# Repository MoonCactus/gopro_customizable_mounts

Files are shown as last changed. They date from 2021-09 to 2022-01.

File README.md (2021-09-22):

This is the **official** and popular "GoPro customizable mounts, and a library to expand"

It is an openscad script than can generate all sorts of custom gopro mounts. This is useful both when space is a constraint and to improve stiffness over complicated multipart "official" gopro linked mount bits.

You can use Thingiverse "customizer" (when it works) to generate all sorts of shapes to suit your needs.

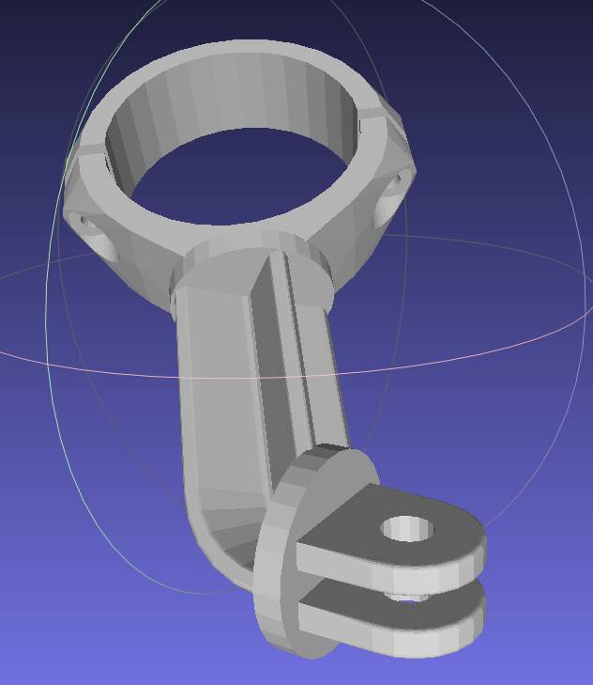
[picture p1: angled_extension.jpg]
Example of generated design


Licence is CC-BY-NC 2013 by jeremie.francois@gmail.com

  * https://www.linkedin.com/in/jeremiefrancois/
  * https://www.thingiverse.com/thing:62800
  * Make yours with https://www.thingiverse.com/apps/customizer/run?thing_id=62800
  * https://www.tridimake.com

It slices neatly with the following parameters

  * 0.1 mm layers (for better look & more compact FDM) -- 0.15 is still OK (and faster)
  * 0.8 mm walls (loops->infill->perimeters)
  * 0.8 mm bottom/top
  * 100% fill (probably safer, though 30% is quite OK)

Better use PETG instead of PLA for heat resistance.

History
  * Rev 1.2: added vvertical angle option for extension, free head rotation and rounded baseplate when needed
  * Rev 1.1: added horizontal angle option for extension
  * Rev 1.03: examples and first release (20130317-1234)
  * Rev 1.02: added handle/bar mount and rounded the angles of the rod mount
  * Rev 1.01: fixed printing angle vs captive nut slot, added a slight freeplay

Example of parameters

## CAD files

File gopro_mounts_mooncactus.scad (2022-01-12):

/* [Main] */

// First head kind ("example" show them all but is not printable)
gopro_primary_kind="triple"; // [example1,example2,triple,double]
// Sedond head kind (only for the triple or double primary kind)
gopro_secondary_kind="tripod_small"; // [double,triple,rod,clamp,tripod_small,tripod_large,plate,none]
// If you rotate the seconday head you will probably need to enable support to print it
gopro_secondary_rotation=0; // [0:180]

// Optional, possibly bent axis-to-axis extension rod (length cannot be less than 21mm).
gopro_ext_len=50;
// Thickness of the extension rod walls (2 to 6mm are good values)
gopro_ext_th=2;
// Angle at the base of the extension
gopro_ext_bend_angle=50; // [0:90]
// Twist at the base of the extension
gopro_ext_twist=0; // [0:180]

// How thick are the mount walls
gopro_wall_th= 3;

/* [Rod and captive nut] */

// This tab is useful only if you have selected "rod" as the secondary head. Optional rod diameter (also the captive nut internal diameter)
gopro_captive_rod_id= 3.8;
// Angle the rod makes with the axis (0 is colinear, 90 is a right angle)
gopro_captive_rod_angle= 45; // [0:90]
// Optional captive nut thickness with freeplay (tightest would be 3.2)
gopro_rod_nut_th= 3.6;
// Optional captive nut diameter with freeplay (from corner to corner)
gopro_rod_nut_od= 8.05;

/* [Clamp/bar mount] */

// This tab is useful only if you have selected "clamp" as the secondary head.  Optional (handle)bar diameter
gopro_bar_rod_d= 35;
// How thick is the ring around the bar
gopro_bar_th= 4;
// How big is the gap between the jaws
gopro_bar_gap= 2;
// Bar screw diameter
gopro_bar_screw_d= 3;
// Diameter of the head of the screw
gopro_bar_screw_head_d= 6.4;
// Diameter of the nut of the screw from corner to corner (can be zero)
gopro_bar_screw_nut_d= 6.25;
// How thick are the shoulders on which to bolt (each side)
gopro_bar_screw_shoulder_th=5;
// Whether to reverse the bolt orientation (from which side you will screw the bolt, defaut is from the joint)
gopro_bar_screw_reversed=0; // [0:false, 1:true]

/* [Baseplate] */

// This tab is useful only if you have selected "plate" as the secondary head. Increase gopro_wall_th for sturdier shape. Plate main length:
plate_len=40;
// Width of the plate, or zero for the exact arm section (it makes the shape easier to print, but a possibly unstable base)
plate_width=0;
// Diameter of the plate screws
plate_screw_d=3.1;
// Distance from screws to the exterior of the baseplate (ie. relative to plate_len)
plate_screw_margin_outer=5;
// Space betwen optional pairs of screws. Zero to have only one screw on each side.
plate_screw_pair_spacing=0;
// Make the screw pairs into slots (needs positive plate_screw_pair_spacing). Useful for straps, for example.
plate_strap_slot=0; // [0:false, 1:true]
// Gap to leave for a strap be be sled between the plate and the rest of the shape (makes it harder to print).
plate_strap_gap=0;

/* [Hidden] */

// The gopro connector itself (you most probably do not want to change this but for the first two)

// The locking nut on the gopro mount triple arm mount (keep it tight)
gopro_nut_d= 9.2;
// How deep is this nut embossing (keep it small to avoid over-overhangs)
gopro_nut_h= 2;
// Hole diameter for the two-arm mount part
gopro_holed_two= 5.2;
// Hole diameter for the three-arm mount part
gopro_holed_three= 5.5;
// Thickness of the internal arm in the 3-arm mount part
gopro_connector_th3_middle= 3.2;
// Thickness of the side arms in the 3-arm mount part
gopro_connector_th3_side= 2.75;
// Thickness of the arms in the 2-arm mount part
gopro_connector_th2= 2.85;
// The gap in the 3-arm mount part for the two-arm
gopro_connector_gap= 2.95;
// How round are the 2 and 3-arm parts
gopro_connector_roundness= 1;

// Hole diameter for small tripod mount screws (tight-fit)
tripod_small_d=5.5;
// Hole diameter for large tripod mount screws (tight-fit)
tripod_large_d=8.4;
// Tripod base height
tripod_screw_depth=12;
// Tripod base diameter
tripod_base_d=25;

// These two settings only helps against geometrical issues (non-manifold), do not change !
gopro_connector_wall_tol=0.5+0;
gopro_tol=0.04+0;

// Can be queried from the outside
gopro_connector_z= 2*gopro_connector_th3_side+gopro_connector_th3_middle+2*gopro_connector_gap;
gopro_connector_x= gopro_connector_z;
gopro_connector_y= gopro_connector_z/2+gopro_wall_th;

///////////////////////////////////////////////////////////////////////
//
// GoPro Hero mount and joint (gopro_mounts_mooncactus.scad) - Rev 1.1
//
///////////////////////////////////////////////////////////////////////
//
// CC-BY-NC 2013 jeremie.francois@gmail.com
// https://www.linkedin.com/in/jeremiefrancois/
// https://www.thingiverse.com/thing:62800
// https://www.tridimake.com

// It slices neatly with the following parameters
//
// 0.1 mm layers (for better look & more compact FDM) -- 0.15 is still OK (and faster)
// 0.8 mm walls (loops->infill->perimeters)
// 0.8 mm bottom/top
// 100% fill (probably safer, though 30% is quite OK)
// Better use PETG instead of PLA for heat resistance.
//
// Rev 1.3: added tripod and base plate end shapes
// Rev 1.2: added vertical angle option for extension, free head rotation and rounded baseplate when needed
// Rev 1.1: added horizontal angle option for extension
// Rev 1.03: examples and first release (20130317-1234)
// Rev 1.02: added handle/bar mount and rounded the angles of the rod mount
// Rev 1.01: fixed printing angle vs captive nut slot, added a slight freeplay

/* ****************************************************************

HOW TO USE IN YOUR OWN DESIGNS

use <gopro_mounts_mooncactus.scad>

// Create a "triple" gopro connector
gopro_connector("triple");

// Create a "triple" gopro connector without the locking nut shape
translate([30,0,0])
	gopro_connector("triple", withnut=false);

// Create a "double" gopro connector
translate([60,0,0])
	gopro_connector("double");

// Add a bar mount/clamp to one of the connector
translate([90,0,0])
gopro_bar_clamp(
	rod_d= 31, // rod diameter
	th= 3.2, // main thickness
	gap= 2.4, // space between the clamps
	screw_d= 3, // screw diameter
	screw_head_d= 6.2, // screw head diameter
	screw_nut_d= 6.01, // nut diameter from corner to corner
	screw_shoulder_th=4.5, // thickness of the shoulder on which the nut clamps
	screw_reversed=false	 // true to mirror the orientation of the clamp bolts
);

// Extends a connector with a mount for a rod and an optional embedded nut
translate([120,0,0])
gopro_rod_connect(
	rod_id=3.8, // rod diameter
	angle=80,  // rod angle (0 is straight, 90 is a right turn)
	nut_th=3.2, // embedded nut thickness (can be zero to disable the embedded nut)
	nut_od=7.9 // nut diameter from corner to corner
);

// How to build a linear extruded bar extender
translate([0,65,0])
{
	gopro_connector("double");
	gopro_extended(len=50, th=3)
		scale([1,-1,1])
				gopro_connector("triple");
}

// The following dimensions are useful to attach the mount to your design:
	gopro_connector_z= 14.7;
	gopro_connector_x= 14.7;
	gopro_connector_y= 10.35;


// Finally, note that the arm are designed in a way which is not the best orientation to print: you would better rotate them with, eg. rotate([0,90,0])

**************************************************************** */



// To generate the sample set in bash, just copy/paste the following in a terminal:
/*
for kind in double triple; do
	for angle in 30 80; do
		through=true
		[[ $angle == 0 ]] && through=false
		openscad -D print_it=true -D gopro_primary_kind="\"$kind\"" -D gopro_captive_rod_angle=$angle -o gmb_${kind}_${angle}.stl gopro_mount_bit.scad
	done
	openscad -D print_it=true -D gopro_primary_kind="\"$kind\"" -D gopro_rod_nut_th=0 -o gmb_${kind}_simple.stl gopro_mount_bit.scad
done
*/

module gopro_more()
{
	for(i=[0:$children-1])
		translate([0,-2*gopro_connector_y,0]) children(i);
}
module gopro_reverse()
{
	for(i=[0:$children-1])
		scale([1,-1,1]) children(i);
}

//
// ================ Full (colored) example (for openscad & command line)
//
gopro_ext_len_real= (gopro_ext_len > 2*gopro_connector_y ? gopro_ext_len : 0);
if(gopro_primary_kind=="example1")
{
	gopro_connector("triple", withnut=true);

	color([1,0.2,0.2])
		gopro_bar_clamp(
			rod_d= gopro_bar_rod_d, th=gopro_bar_th, gap=gopro_bar_gap,
			screw_d= gopro_bar_screw_d, screw_head_d= gopro_bar_screw_head_d, screw_nut_d= gopro_bar_screw_nut_d, screw_shoulder_th= gopro_bar_screw_shoulder_th,
			screw_reversed= gopro_bar_screw_reversed	);

			
	rotate([0,180,130]) color([0.2,0.2,1])
		gopro_connector("double");
		
	rotate([0,180,130]) color([0,0.8,0])
		gopro_rod_connect(nut_th=gopro_rod_nut_th, nut_od=gopro_rod_nut_od, rod_id=gopro_captive_rod_id, angle=gopro_captive_rod_angle);
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

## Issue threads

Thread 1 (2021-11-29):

Problem with "Tripod" mount

rarroyo6, 2021-11-29:
When the tripod mount is rendered (in scad or in the thingiverse customizer), it shows several rods sticking out of the base, and it does not have a screw hole for the tripod.

MoonCactus, 2021-11-30:
You are right, thanks for telling me. I wonder what I was doing (probably debugging)
I just fixed it.

Closed 2021-11-30.

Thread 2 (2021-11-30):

Problem with "Rod" mount

rarroyo6, 2021-11-30:
When the Rod mount is rendered, the "hole" for the rod  sticks out rather than going inward.
Similar to the issue the tripod mount had. (Thanks for fixing that).

MoonCactus, 2021-11-30:
Indeed, same problem (what the heck?) :D
Fixed - Thanks for testing, so I focus on fixing the bugs that should not exist in the first place ;)

rarroyo6, 2021-12-01:
Thanks, I'm using it to mount some cameras flashes to my tripod and they fit perfectly.
By coincidence, I needed both the tripod mount and the rod mount. All's great now. :)

MoonCactus, 2021-12-01:
Glad it suits you ! Actually it is the first time I get feedback for these specific mounts though this old design has ~100K views and 50K downloads on thingiverse (this is just amazing). I designed the rod mount specifically for versatile photo setups.
Would you be ok to send me a picture & allow me to add it on thingiverse or this wiki ? jeremie francois at gmail

Closed 2021-11-30.

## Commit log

2021-09-22 Created by gitinit 20210922-094342
    [gopro_mounts_mooncactus.scad]
2021-09-22 Added free rotation of heads and extension arm, reduce tightness of fingers
    [gopro_mounts_mooncactus.scad]
2021-09-22 Added README.md for github
    [gopro_mounts_mooncactus.scad]
2021-09-22 Added "tripod_small" and "tripod_large" options
    [gopro_mounts_mooncactus.scad]
2021-09-22 Cosmetic renaming
    [gopro_mounts_mooncactus.scad]
2021-09-22 Extended angle ranges for thingiverse customizer, renamed a variable (twist better than rotate)
    [gopro_mounts_mooncactus.scad]
2021-09-22 Added new shape "plate" for straps and screwed installation
    [gopro_mounts_mooncactus.scad]
2021-09-22 Simulate booleans with 0,1 integers to stay compatibile with the feeble thingiverse customizer
    [gopro_mounts_mooncactus.scad]
2021-11-30 Fix: subtract tripod notches (not add!)
    [gopro_mounts_mooncactus.scad]
2021-11-30 Fix: subtract rod center (not add, wtf happended?)
    [gopro_mounts_mooncactus.scad]
2022-01-12 Fix for the customizer (arm length not showing)
    [gopro_mounts_mooncactus.scad]
